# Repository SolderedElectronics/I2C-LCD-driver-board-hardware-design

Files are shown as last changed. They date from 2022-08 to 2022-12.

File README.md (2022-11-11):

# I2C LCD driver board Hardware design

## About the product

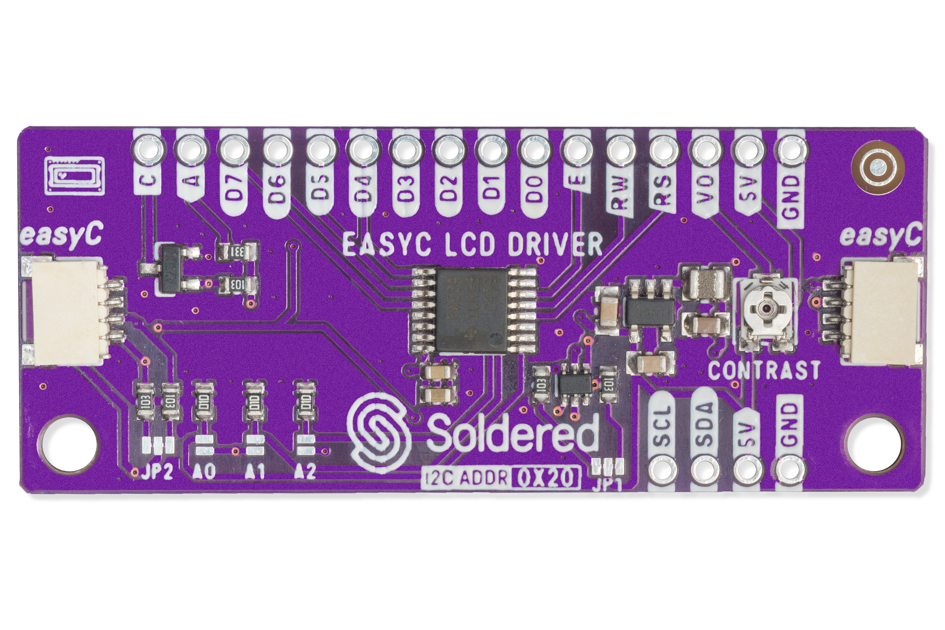
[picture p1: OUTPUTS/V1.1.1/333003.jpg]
I2C LCD driver board
|  |
| :----------------------------------------------------------: |
|      [Buy I2C LCD driver board](https://www.solde.red/333003)      |

This adapter makes connection of LCD to Dasduino (or any other Arduino-compatible board) a breeze! It uses I2C communication which needs only two pins. It can be used and work with all of ours LCDs (16x2, 20x4, 16x4). Use our library and get started in few minutes of work!

It's even easier with easyC - no soldering is needed!

## Repository contents

All Soldered Electronics hardware designed in KiCAD, and repositories are organized in the following way:

- CAD folder - contains KiCAD files (Schematics, Board, Panel Board), sorted by version. Change log lists all changes between versions.
- OUTPUTS - contains useful files, such as Bill of Materials (BOM), PDF of schematics, 3D .step file of the board and gerber files, sorted by version. 
- OUTPUTS -> Compliance - Certificates and useful legal stuff. 

## Want to contribute?

Please feel free to submit a pull request if you have any contributions. We encourage you to submit an issue or pull request if you find a bug. 

## About Soldered

soldered-logo

At Soldered, we design and manufacture a wide selection of electronic products to help you turn your ideas into acts and bring you one step closer to your final project. Our products are intented for makers and crafted in-house by our experienced team in Osijek, Croatia. We believe that sharing is a crucial element for improvement and innovation, and we work hard to stay connected with all our makers regardless of their skill or experience level. Therefore, all our products are open-source. Finally, we always have your back. If you face any problem concerning either your shopping experience or your electronics project, our team will help you deal with it, offering efficient customer service and cost-free technical support anytime. Some of those might be useful for you:

- [Web Store](https://www.soldered.com/shop)
- [Tutorials & Projects](https://soldered.com/learn)
- [Community & Technical support](https://soldered.com/community)

## License info

All Soldered open-source hardware (OSH) is under The TAPR Open Hardware License. Read more in the LICENSE file. 

No warranty - all designs in this repository are distributed in the hope that they will be useful, but without any warranty. They are provided "AS IS", therefore without warranty of any kind, either expressed or implied. The entire quality and performance of what you do with the contents of this repository are your responsibility. In no event, Soldered Electronics will be liable for your damages, losses, including any general, special, incidental or consequential damage arising out of the use or inability to use the contents of this repository. 

## Have fun! 
And thank you from your fellow makers at Soldered Electronics.

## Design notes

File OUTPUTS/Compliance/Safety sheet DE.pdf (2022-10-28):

## Einhaltung gesetzlicher Vorschriften und wichtige Sicherheitsinformationen

BITTE BEWAHREN SIE DIESE INFORMATIONEN ZUR SPÄTEREN VERWENDUNG AUF.

LESEN SIE VOR DER VERWENDUNG DIESES PRODUKTS ALLE ANWEISUNGEN IN DOKUMENT.

Produktname: | I2C LCD driver board
Die ersten Schritte: | Besuchen Sie www.soldered.com, um loszulegen.

# WARNUNGEN

- Dieses Produkt sollte nicht abgedeckt werden und in einer gut belüfteten Umgebung betrieben werden.
- Das Produkt sollte auf einer stabilen, flachen, nicht leitenden Oberfläche aufgestellt werden und nicht mit leitenden Gegenständen in Berührung kommen.
- Der Anschluss anderer Geräte kann die Konformität beeinträchtigen oder zu Schäden am Gerät führen und zum Erlöschen der Garantie führen.
- Wenn Peripheriegeräte angeschlossen werden, die nicht das Kabel oder den Stecker enthalten, muss das verwendete Kabel oder muss das verwendete Kabel bzw. der verwendete Steckverbinder eine angemessene Isolierung und Funktion aufweisen, damit die Anforderungen die einschlägigen Leistungs- und Sicherheitsanforderungen erfüllt werden.
- Es besteht Explosionsgefahr, wenn die Batterie falsch eingesetzt wird.
- Das Produkt sollte nicht außerhalb des angegebenen Arbeitsbereichs verwendet werden.

# HINWEISE ZUR SICHEREN ANWENDUNG

Um Fehlfunktionen oder Schäden an Ihrem Gerät zu vermeiden, beachten Sie bitte die folgenden Hinweise:
- Setzen Sie das Gerät nicht Wasser oder Feuchtigkeit aus und stellen Sie es nicht auf eine
leitende Oberfläche, wenn es eingeschaltet ist. Das Gerät nicht mit nassen Händen anfassen.
- Setzen Sie es keiner Wärmequelle aus; das Produkt ist für die Verwendung bei normalen Raumtemperaturen ausgelegt. Das Produkt ist für die Verwendung in Innenräumen vorgesehen.
- Seien Sie bei der Handhabung vorsichtig, um mechanische oder elektrische Schäden an Teilen des Geräts zu vermeiden. Fassen Sie das Gerät nicht an, wenn es unter Spannung steht. Verwenden Sie einen ESD-Schutz.
- Verwenden Sie nur das mitgelieferte Kabel (oder ein gleich- oder höherwertiges Kabel)
mit dem Gerät.

# COMPLIANCE-INFORMATIONEN

Das Produkt entspricht den entsprechenden Bestimmungen der RoHS-Richtlinie für die Europäische Union. Wie alle elektrischen und elektronischen Geräte (EEE), sollte das Produkt nicht über den Hausmüll entsorgt werden.
ELEKTROMAGNETISCHE VERTRÄGLICHKEIT UND BETRIEB
- Das Produkt entspricht den Schutzanforderungen der Richtlinie des EU-Rates 2014/30/EU über die Rechtsvorschriften der Mitgliedstaaten zur elektromagnetischen Verträglichkeit und den Elektromagnetische Verträglichkeitsverordnung 2016 des Vereinigten Königreichs.
- WARNUNG: Bitte verändern Sie nicht das Design dieses Produkts, da dies dazu führen kann, dass Sie das Produkt nicht mehr uneingeschränkt nutzen können.
Dies gilt auch für die Änderung der Frequenz, mit der das Produkt arbeitet.

Soldered Electronics d.o.o., Reisnerova ulica 100, 31000 Osijek, Croatia. VAT ID: HR83200237288

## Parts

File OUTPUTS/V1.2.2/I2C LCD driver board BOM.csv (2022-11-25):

Id | Designator | Package | Quantity | Designation | Supplier and ref
1 | K5 | HEADER_MALE_4X1 | 1 | HEADER_MALE_4X1
2 | K1,K2 | easyC-connector | 2 | easyC-SMD
3 | C4 | 0603C | 1 | 100n
4 | U1 | TSSOP-16 | 1 | TCA9534PWR
5 | R2,R1,R3 | 0603R | 3 | 100k
6 | JP4,JP3,JP5 | SMD_JUMPER | 3 | SMD_JUMPER
7 | C2,C1 | 0805C | 2 | CL10A226MPCNUBE
8 | Q1 | SOT-23-3 | 1 | NMOS
9 | R8,R10,R9,R6,R4 | 0603R | 5 | 10k
10 | JP1,JP2 | SMD_JUMPER_3_PAD_TRACE | 2 | SMD_JUMPER_3_PAD_TRACE
11 | R5 | 0603R | 1 | 0R
12 | U2 | tps613222a | 1 | TPS613222A
13 | C3 | 0603C | 1 | 1u
14 | U3 | SOT-363 | 1 | NMOS-DUAL
15 | H2,H1 | HOLE_3.2mm | 2 | HOLE_3.2mm
16 | L1 | 0806L | 1 | DFE201612E-2R2M=P2
17 | R7 | tc33x-2-103e | 1 | tc33x-2-103e
18 | C5 | 0805C | 1 | C1608X7S1A475K080AC
19 | K3,K4 | HEADER_MALE_8X1 | 2 | HEADER_MALE_8X1

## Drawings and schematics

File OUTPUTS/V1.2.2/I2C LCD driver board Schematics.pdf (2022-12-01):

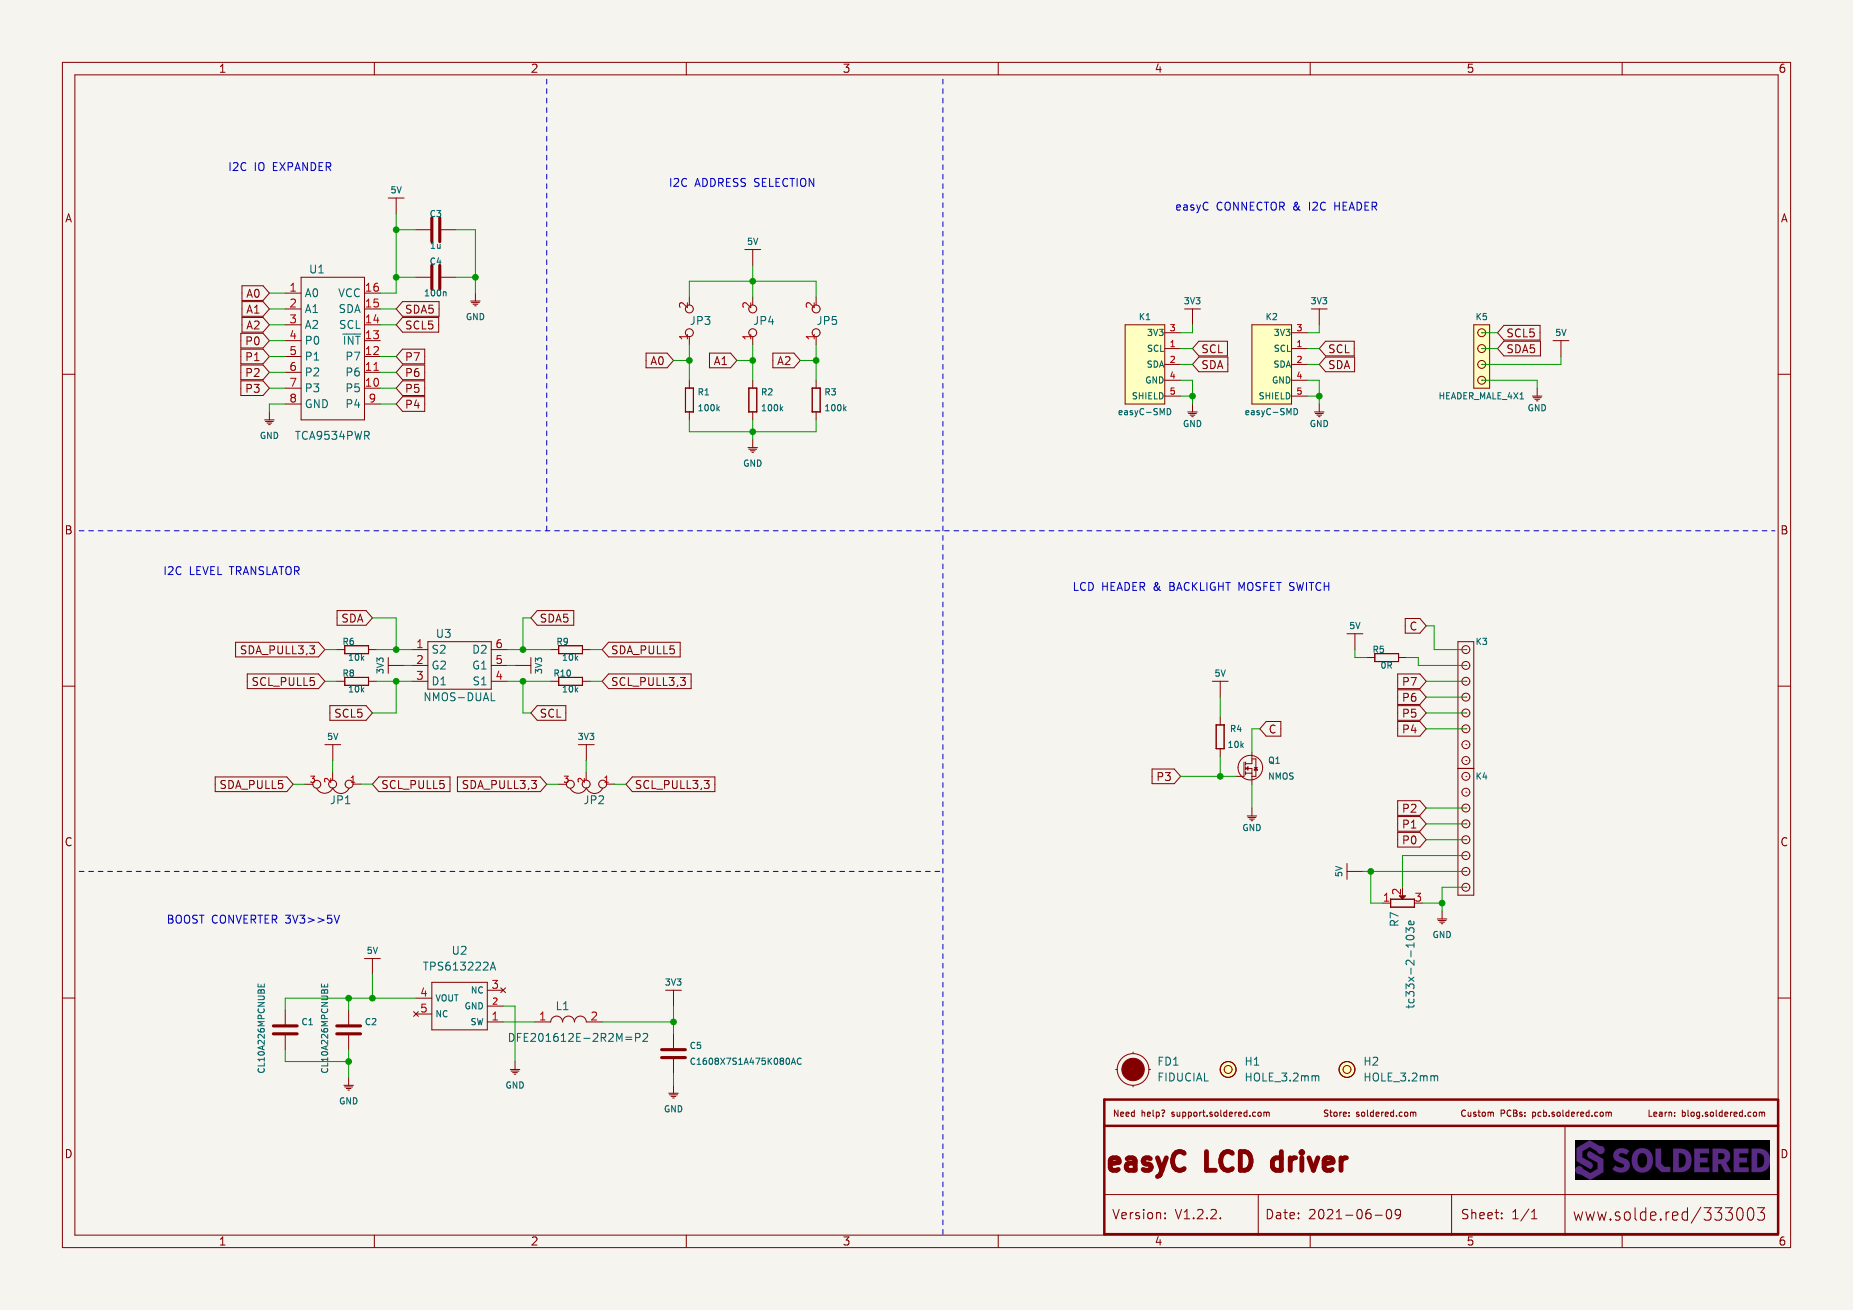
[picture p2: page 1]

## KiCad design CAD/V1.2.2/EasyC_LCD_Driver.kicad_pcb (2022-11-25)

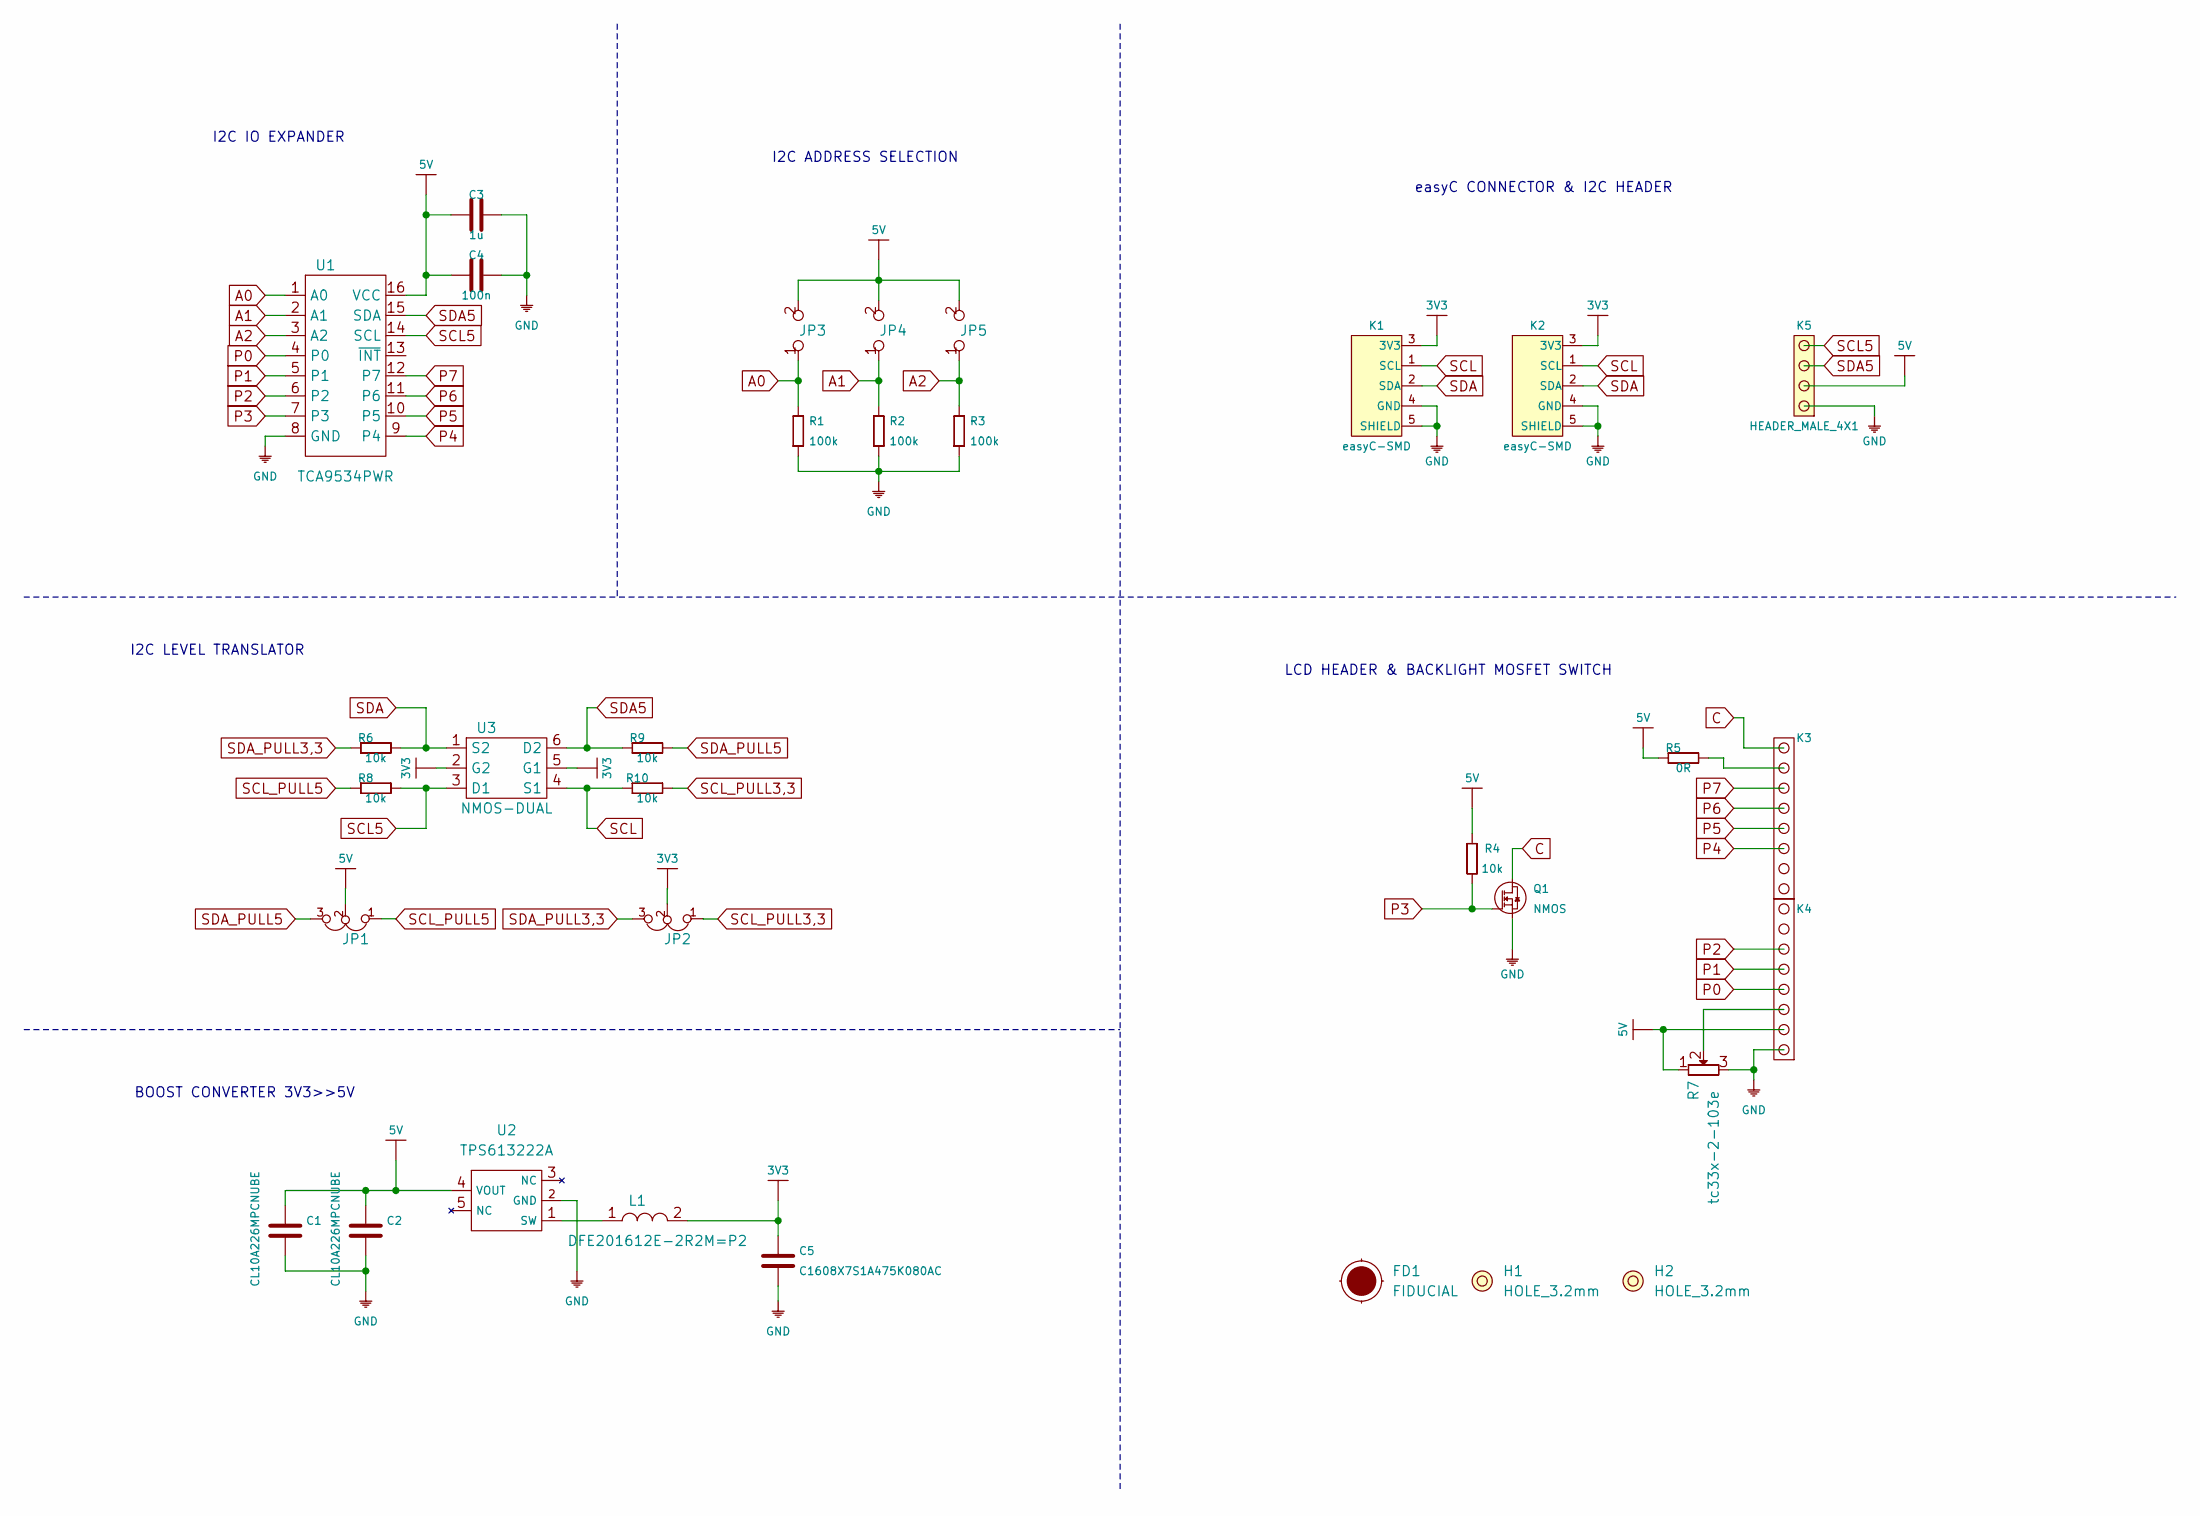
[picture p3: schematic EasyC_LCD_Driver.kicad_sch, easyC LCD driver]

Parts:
C1, C2: CL10A226MPCNUBE; 0805C
C3: 1u; 0603C
C4: 100n; 0603C
C5: C1608X7S1A475K080AC; 0805C
FD1: FIDUCIAL; FIDUCIAL_23
H1, H2: HOLE_3.2mm
JP1, JP2: SMD_JUMPER_3_PAD_TRACE
JP3, JP4, JP5: SMD_JUMPER
K1, K2: easyC-SMD; easyC-connector
K3, K4: HEADER_MALE_8X1
K5: HEADER_MALE_4X1
L1: DFE201612E-2R2M=P2; 0806L
Q1: NMOS; SOT-23-3
R1, R2, R3: 100k; 0603R
R4, R6, R8, R9, R10: 10k; 0603R
R5: 0R; 0603R
R7: tc33x-2-103e
U1: TCA9534PWR; TSSOP-16
U2: TPS613222A; tps613222a
U3: NMOS-DUAL; SOT-363

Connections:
3V3: C5.2, JP2.2, K1.3 (3V3), K2.3 (3V3), L1.2, U3.2 (G2), U3.5 (G1)
5V: C1.2, C2.2, C3.1, C4.1, JP1.2, JP3.2, JP4.2, JP5.2, K4.2, K5.2, R4.1, R5.1, R7.1, U1.16 (VCC), U2.4 (VOUT)
A0: JP3.1, R1.2, U1.1 (A0)
A1: JP4.1, R2.2, U1.2 (A1)
A2: JP5.1, R3.2, U1.3 (A2)
C: K3.8, Q1.3 (D)
GND: C1.1, C2.1, C3.2, C4.2, C5.1, K1.4 (GND), K1.5 (SHIELD), K2.4 (GND), K2.5 (SHIELD), K4.1, K5.1, Q1.2 (S), R1.1, R2.1, R3.1, R7.3, U1.8 (GND), U2.2 (GND)
unnamed: K3.7, R5.2
unnamed: K4.3, R7.2
unnamed: L1.1, U2.1 (SW)
P0: K4.4, U1.4 (P0)
P1: K4.5, U1.5 (P1)
P2: K4.6, U1.6 (P2)
P3: Q1.1 (G), R4.2, U1.7 (P3)
P4: K3.3, U1.9 (P4)
P5: K3.4, U1.10 (P5)
P6: K3.5, U1.11 (P6)
P7: K3.6, U1.12 (P7)
SCL: K1.1 (SCL), K2.1 (SCL), R10.1, U3.4 (S1)
SCL5: K5.4, R8.2, U1.14 (SCL), U3.3 (D1)
SCL_PULL3,3: JP2.1, R10.2
SCL_PULL5: JP1.1, R8.1
SDA: K1.2 (SDA), K2.2 (SDA), R6.2, U3.1 (S2)
SDA5: K5.3, R9.1, U1.15 (SDA), U3.6 (D2)
SDA_PULL3,3: JP2.3, R6.1
SDA_PULL5: JP1.3, R9.2

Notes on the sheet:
I2C ADDRESS SELECTION
I2C IO EXPANDER
LCD HEADER & BACKLIGHT MOSFET SWITCH
easyC CONNECTOR & I2C HEADER
I2C LEVEL TRANSLATOR
BOOST CONVERTER 3V3>>5V

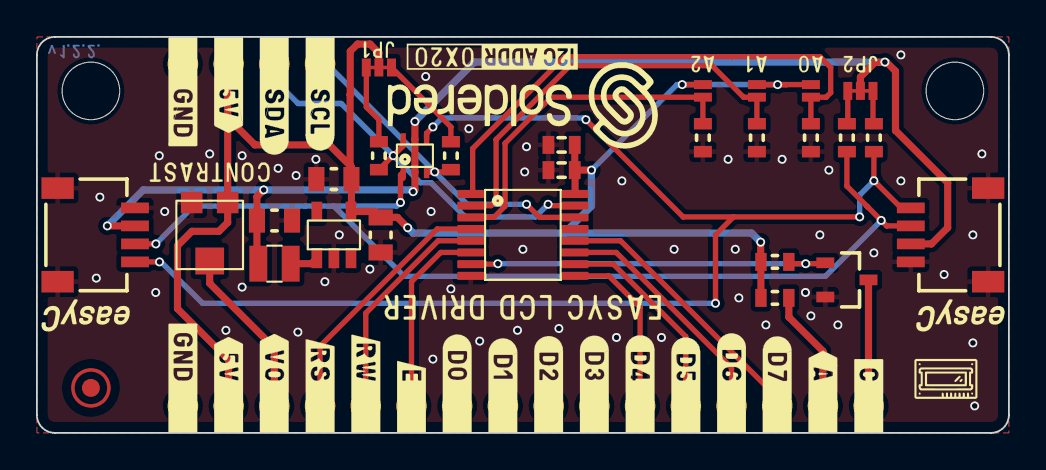
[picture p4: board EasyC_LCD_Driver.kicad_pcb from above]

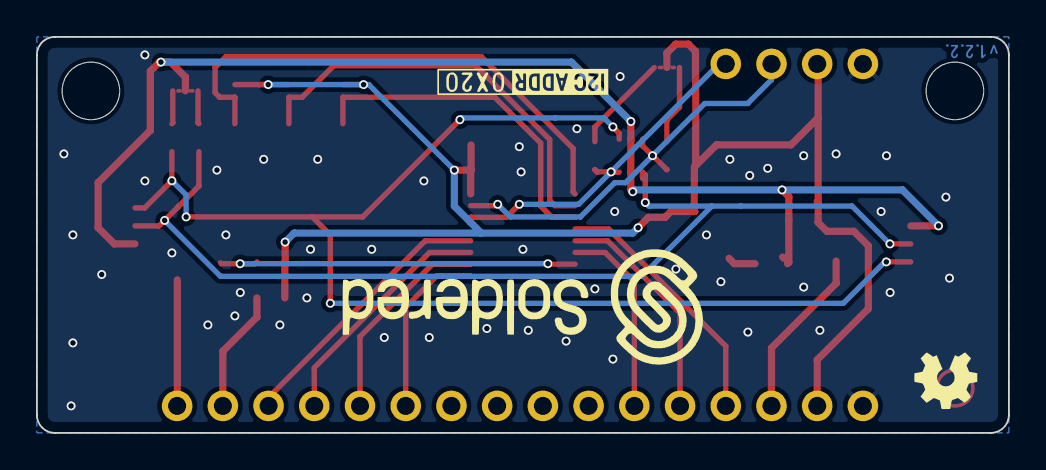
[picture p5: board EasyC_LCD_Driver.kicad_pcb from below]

Board: 2 copper layers, 54.0 x 22.0 mm, 33 parts (2 on the bottom side), 26 nets.

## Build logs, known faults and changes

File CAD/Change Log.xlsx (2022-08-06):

CHANGE LOG
 | Latest version |  |  | v1.1.1.
 |  | Product name: |  | EASYC_LCD_DRIVER
 |  | Release date: |  | 14.4.2021.
 |  | Release author: |  | Ivan
Version: | v1.0.0. | Author: | Ivan | Date: | 14.4.2021.
List of Changes
 | Initial document
Version: | v1.1.1. | Author: | Ivan | Date: | 9.6.2021.
List of Changes
 | Promjenjen logo back na veličinu 20
 | promjenjene linije SDA5 i SCL5 na level translatoru i odgovarajuči pull-up otpornici jer je bilo krivo spojeno na mosfet
 | Na IC spojene 5V I2C linije, a ne 3V3 linije kako je bilo na prvoj verziji
 | Zavojnica za boost 3V3 na 5V povečan footprint i stavljeni 0805 footprinti za kondenzatore koji su 0603 jer su veliki za 0603 footprint
 | Stavljene veće oznake za jumpere
 | Kod potenciometra umjesto POT1 stavljena oznaka CONTRAST
 | Dodana LCD ikonica
 | Dodan novi FIDUCIAL
 | Dodana I2C adresa na prednju stranu
Version: | v1.2.2. | Author: | Ivan Fadiga | Date: | 27.4.2022.
List of Changes
 | Changed R5 to 0R
